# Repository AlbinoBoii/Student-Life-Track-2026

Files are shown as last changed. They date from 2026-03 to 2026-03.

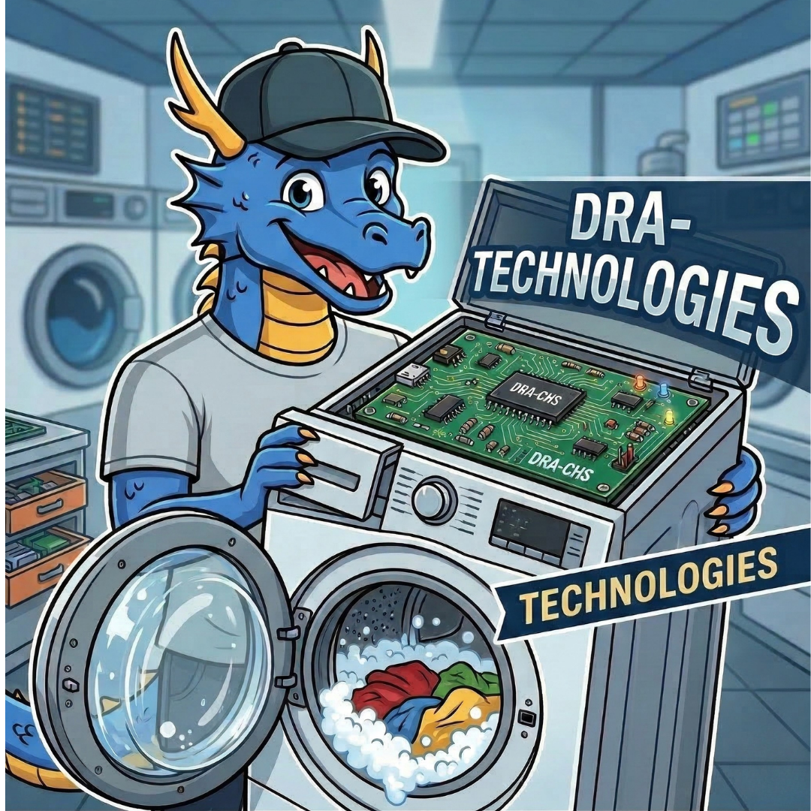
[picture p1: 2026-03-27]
Images/drawasher.png

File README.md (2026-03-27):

# 🧺 Dra-Washer Monitor – Smart Washing Machine Cycle Detection

A complete end-to-end IoT solution that transforms your **ordinary washing machine** into a smart appliance. Using an ESP32 microcontroller and vibration sensors, the system detects wash cycles in real-time and provides a powerful dashboard for monitoring and ML-based cycle classification.

**Perfect for**: Dorm laundry tracking, shared housing, smart home enthusiasts, IoT/ML learning projects.

---

## 🚀 Quick Start (5 Minutes)

### 1. **Access the Dashboard**
- Navigate to: `https://<your-azure-function-url>/api/dashboard`
- You'll see live streaming data from your ESP32

### 2. **Check Device Status**
- Look at the top-right corner for the **Online/Offline indicator**
- 🟢 Green = Device connected and sending data
- 🔴 Red = No data for 10+ minutes

### 3. **Explore Three Tabs**
- **Live**: Real-time washing machine vibration (refreshes every 10 seconds)
- **Historical**: Browse past cycles with date/time filters
- **ML Training**: Label historical data to train custom models

---

## 📋 Table of Contents

- [What is the Dra-Washer Monitor?](#what-is-the-dra-washer-monitor)
- [System Architecture](#system-architecture)
- [Getting Started](#getting-started)
- [Using the Dashboard](#using-the-dashboard)
- [Data Analysis & Aggregation](#-data-analysis--aggregation)
- [ML Training Pipeline](#ml-training-pipeline)
- [Project Structure](#project-structure)
- [Troubleshooting](#troubleshooting)
- [Contributing](#contributing)

---

## 💡 What is the Dra-Washer Monitor?

The **Dra-Washer Monitor** is a four-part system:

1. **Edge Device (ESP32)**: Collects vibration data via an accelerometer attached to the washing machine
2. **Cloud Backend (Azure)**: Stores data securely and provides a REST API
3. **Web Dashboard**: Real-time monitoring, historical analysis, and **interactive ML training**
4. **ML Pipeline**: Train custom models on your washing machine's unique vibration signature and deploy them back to the ESP32

### Why This Matters
- 🎯 **Solves a real problem**: Know when your laundry is done without constant checking
- 🔬 **Learn full-stack IoT**: Signal processing, cloud architecture, ML, and embedded systems
- 📊 **Your data, your model**: Train on your specific washing machine, not cloud-based generic models
- 💰 **Ultra-affordable**: Using existing hardware; only Azure Table Storage costs pennies per month

---

## 🏗️ System Architecture

```
┌─────────────────────────────────────────────────────────────────┐
│                        YOUR WASHING MACHINE                      │
│  ┌──────────────────────────────────────────────────────────┐   │
│  │  ESP32 + MPU6050 Accelerometer (10Hz sampling)          │   │
│  │  • Raw acceleration (ax, ay, az)                         │   │
│  │  • Compute motion_score & motion_avg                     │   │
│  │  • State machine (IDLE/RUNNING/SPINDRY)                  │   │
│  └──────────────┬───────────────────────────────────────────┘   │
└─────────────────┼──────────────────────────────────────────────┘
                  │ HTTP POST (every 2.5 sec during cycles)
                  │ Batched sensor data + device_id
                  ▼
        ┌─────────────────────┐
        │  Azure Functions    │
        │  /api/ingest → POST │
        │  /api/samples → GET │
        │  /api/label → PATCH │
        │  /api/dashboard→GET │
        └──────────┬──────────┘
                   │
        ┌──────────▼──────────┐
        │ Azure Table Storage │
        │   (washersensordata)│
        │  Stores all telemetry
        │  & user labels      │
        └──────────┬──────────┘
                   │
        ┌──────────▼──────────────────┐
        │   Your Web Browser (or app) │
        │                             │
        │  📊 Live Tab                │
        │    - Real-time charts       │
        │    - Device status          │
        │                             │
        │  📈 Historical Tab          │
        │    - Date range filters     │
        │    - Motion analysis        │
        │                             │
        │  🤖 ML Training Tab         │
        │    - Label cycles           │
        │    - Export CSV             │
        └──────────┬──────────────────┘
                   │
        ┌──────────▼──────────────────┐
        │   Local ML Training         │
        │   (train_model.py)          │
        │                             │
        │  1. Load labeled CSV        │
        │  2. Train Random Forest     │
        │  3. Evaluate metrics        │
        │  4. Generate C++ header     │
        └──────────┬──────────────────┘
                   │
        ┌──────────▼──────────────────┐
        │  Deploy to ESP32            │
        │  washer_model.h             │
        │  ↓                          │
        │  Custom cycle detection!    │
        └─────────────────────────────┘
```

---

## 🛠️ Getting Started

### Prerequisites
- **ESP32 Development Board** (any variant)
- **MPU6050 Accelerometer** module
- **Micro USB cable** for ESP32 programming
- **WiFi network** with internet access
- **Azure account** (for cloud backend)
- **Python 3.8+** (for ML training)

---

## ⚙️ Configuration Files (Create These Before Deployment)

### 1. ESP32 Secrets File
Create `washer_monitor/secrets.h` with your WiFi and API credentials. The firmware is configured for **Enterprise WiFi (PEAP)** (common in university campuses like NUS).

```cpp
#pragma once

// WiFi Configuration (Enterprise / PEAP)
#define WIFI_SSID     "your_wifi_name"
#define EAP_IDENTITY  "your_student_id@domain.edu"
#define EAP_USERNAME  "your_student_id@domain.edu"
#define EAP_PASSWORD  "your_portal_password"

// Azure Function API
#define AZURE_FUNCTION_URL "https://your-function.azurewebsites.net/api/ingest"
#define AZURE_API_KEY      "your-random-api-key-here"

// Telegram Notifications (Optional)
#define BOT_TOKEN "your_telegram_bot_token"
#define CHAT_ID   "your_telegram_chat_id"
```

> [!WARNING]
> These files are listed in `.gitignore` to prevent them from being committed to GitHub. However, they remain in your local folder. **Before zipping or sharing your project folder, ensure these files are removed!**

**Where to get these:**
- **WIFI_SSID/WIFI_PASSWORD**: Your home/dorm WiFi credentials
- **API_ENDPOINT**: Deployed Azure Function URL (you'll get this after Step 1 below)
- **INGEST_API_KEY**: Create a strong random string (e.g., `openssl rand -hex 32`)
- **TELEGRAM_BOT_TOKEN/CHAT_ID**: Optional - get from @BotFather on Telegram

### 2. Azure Functions Local Settings
Create `Azure/local.settings.json` for local development (excluded from git):

```json
{
  "IsEncrypted": false,
  "Values": {
    "AzureWebJobsStorage": "DefaultEndpointsProtocol=https;AccountName=yourstorageaccount;AccountKey=your-account-key;EndpointSuffix=core.windows.net",
    "AZURE_STORAGE_CONNECTION_STRING": "DefaultEndpointsProtocol=https;AccountName=yourstorageaccount;AccountKey=your-account-key;EndpointSuffix=core.windows.net",
    "INGEST_API_KEY": "your-strong-random-api-key-here",
    "FUNCTIONS_WORKER_RUNTIME": "python"
  },
  "Host": {
    "CORS": "*"
  }
}
```

**Where to get these:**
- **AccountName**: Your Azure Storage account name
- **AccountKey**: Primary access key from Storage account → Access keys
- **AZURE_STORAGE_CONNECTION_STRING**: Full connection string from the same location
- **INGEST_API_KEY**: Must match the value in `secrets.h` above

**IMPORTANT**: Never commit these files to git. They're already in `.gitignore`.

---

### Step 1: Deploy Azure Backend

1. **Clone this repository**
   ```bash
   git clone https://github.com/yourusername/Student-Life-Track-2026.git
   cd Student-Life-Track-2026
   ```

2. **Create `Azure/local.settings.json`** (see [Configuration Files](#-configuration-files-create-these-before-deployment) section above)

3. **Deploy Azure Functions** 
   - Option A: Using Azure CLI
     ```bash
     cd Azure
     az login
     az functionapp create --resource-group <your-rg> --consumption-plan-location <region> --runtime python --functions-version 4 --name <your-function-name>
     az functionapp deployment source config-zip --resource-group <your-rg> --name <your-function-name> --src-path function.zip
     ```
   - Option B: Using Azure Portal
     - Create a Function App resource
     - Upload the Python code from `Azure/function_app.py`
     - Set Application Settings with values from `local.settings.json`

4. **Note your Function URL**
   - It will be: `https://<your-function-name>.azurewebsites.net`
   - Copy this to `washer_monitor/secrets.h` as `API_ENDPOINT`

### Step 2: Flash ESP32 Firmware

1. **Open Arduino IDE** and install ESP32 board support
   ```
   Board Manager → ESP32 by Espressif
   ```

2. **Open `washer_monitor/washer_monitor.ino`**

3. **Edit `washer_monitor/secrets.h`** with your credentials:
   ```cpp
   #define WIFI_SSID      "Your_WiFi_Name"
   #define EAP_PASSWORD   "Your_Password"
   #define AZURE_FUNCTION_URL "https://<function-name>.azurewebsites.net/api/ingest"
   #define AZURE_API_KEY      "your-api-key-from-above"
   ```

4. **Connect MPU6050 to ESP32:**
   ```
   MPU6050 → ESP32
   VCC     → 3.3V
   GND     → GND
   SCL     → GPIO 22
   SDA     → GPIO 21
   ```

5. **Upload to ESP32:**
   - Select Board: "ESP32 Dev Module" (or your variant)
   - Select COM port
   - Click Upload

### Step 3: Monitor Live Data

1. Open your browser: `https://<function-name>.azurewebsites.net/api/dashboard`
2. Tap/vibrate the ESP32 to see live motion data
3. Check the device status indicator (top-right)

---

## 📊 Using the Dashboard

### Live Tab
**Real-time monitoring of your washing machine**

```
Controls:
  • Device ID: Filter by device (default: "ESP32 Washer Monitor")
  • Refresh Rate: 5s, 10s, 30s, or 1 minute
  • Backgrounds: Toggle state coloring

Display:
  • Motion Score chart (blue line)
  • 10-second average motion (orange line)
  • Colored backgrounds (green=IDLE, red=RUNNING)
  • Statistics: Total samples, avg motion, running %, etc.
```

### Historical Tab
**Review and analyze past cycles**

```
Filters:
  • Date range: Set "Since" and "Until" timestamps
  • State filter: Show only IDLE or RUNNING cycles
  • Limit: Max 10,000 samples

Actions:
  • Load Data: Fetch matching samples
  • ⬇ CSV: Export as CSV for external analysis
```

### ML Training Tab
**Build custom cycle detection for your machine**

```
Workflow:
  1. Set date filters for data you want to label
  2. Click "📂 Load Data" to load that period
  3. Click-and-drag on the motion chart to select a time range
  4. Choose label: IDLE, WASH, or SPINDRY
  5. Click "Apply Label"
  6. Repeat until you've labeled 30-50 samples of each state
  7. Click "⬇ Labelled CSV" to download

What Each Label Means:
  • IDLE: Machine at rest (baseline vibration)
  • WASH: Main wash cycle (moderate vibration)
  • SPINDRY: High-speed spin-dry (intense vibration)
```

---

## 📊 Data Analysis & Aggregation

### Time-Based Aggregation

Compress large datasets into meaningful time buckets for trend analysis:

```
Query: GET /api/samples?device_id=ESP32&aggregate=5m&format=json

Response:
{
  "count": 288,
  "aggregated": true,
  "bucket_size": "5m",
  "samples": [
    {
      "ts_ms": 1710748800000,
      "motion_score_avg": 2.45,
      "motion_score_min": 0.1,
      "motion_score_max": 8.2,
      "ax_avg": 0.15, "ax_min": -1.2, "ax_max": 1.1,
      "ay_avg": -0.05, "ay_min": -0.8, "ay_max": 0.9,
      "az_avg": 9.82, "az_min": 9.5, "az_max": 10.1,
      "motion_avg_avg": 1.8,
      "sample_count": 300,
      "running_percent": 45.5,
      "sub_state_modes": {"IDLE": 120, "WASH": 150, "SPINDRY": 30}
    },
    ...
  ]
}
```

#### Supported Aggregation Intervals

| Interval | Use Case | Typical Points for 24h |
|---|---|---|
| `1m` | Fine-grained analysis | 1,440 |
| `5m` | Cycle detection patterns | 288 |
| `15m` | Daily trends | 96 |
| `1h` | Long-term statistics | 24 |

**What Gets Aggregated:**
- **Motion metrics**: average, min, max of motion_score and motion_avg
- **Accelerometer axes**: average, min, max for ax, ay, az
- **State analysis**: percentage of time in RUNNING state
- **Sub-state distribution**: count of IDLE/WASH/SPINDRY samples
- **Sample metadata**: total samples in bucket

### Device Health Monitoring

Get comprehensive device uptime and reliability metrics:

```bash
# Query device health for last 7 days
curl "https://<your-function>/api/device-health?device_id=ESP32&days=7"
```

Response includes:

```json
{
  "device_id": "ESP32",
  "total_uptime_seconds": 604800,
  "uptime_percent": 98.5,
  "total_boots": 2,
  "boot_events": [
    {
      "boot_id": "abc123",
      "boot_ts": "2026-03-11T10:00:00+00:00",
      "samples_count": 15000,
      "last_activity": "2026-03-12T14:30:00+00:00"
    }
  ],
  "data_gaps": [
    {
      "start": "2026-03-12T05:00:00+00:00",
      "end": "2026-03-12T05:45:00+00:00",
      "duration_seconds": 2700,
      "reason": "No data (likely offline or power loss)"
    }
  ],
  "wifi_signal_stats": {
    "avg_rssi": -67,
    "min_rssi": -85,
    "max_rssi": -45,
    "samples_with_signal": 14500
  },
  "last_contact": {
    "timestamp": "2026-03-18T14:22:15+00:00",
    "age_seconds": 45,
    "status": "online"
  }
}
```

**Health Metrics Explained:**
- **uptime_percent**: % of observation period device was actively sending data
- **total_boots**: Number of device restarts detected
- **data_gaps**: Periods > 5 minutes without activity (potential issues)
- **wifi_signal_stats**: WiFi signal strength (RSSI) in dBm
  - `-67 dBm`: Strong signal
  - `-85 dBm`: Weak signal (consider repositioning)
- **last_contact**: When device was last heard from; "offline" if > 10 minutes

### Export Data for Analysis

#### CSV Export

```bash
# Download 24h of aggregated data as CSV
curl "https://<your-function>/api/samples?device_id=ESP32&aggregate=1h&format=csv&since=2026-03-18T00:00:00Z&until=2026-03-19T00:00:00Z" \
  > washer_analysis.csv
```

The CSV includes all aggregated columns and is ready for import into Excel, Python, or Tableau.

#### JSON Export (Large Datasets)

```bash
# Raw JSON with full detail (can handle large responses)
curl "https://<your-function>/api/samples?device_id=ESP32&format=json&limit=50000"
```

### Practical Examples

#### Track Washing Machine Usage Over Time

```bash
# Get hourly aggregation for the past week
curl "https://<your-function>/api/samples?device_id=ESP32&aggregate=1h&since=2026-03-11T00:00:00Z"
```

Use this to:
- Identify peak laundry times
- Calculate total RUNNING time per day
- Spot anomalies in vibration patterns

#### Monitor Device Reliability

```bash
# Check if device is healthy
curl "https://<your-function>/api/device-health?device_id=ESP32&days=30"
```

Look for:
- `uptime_percent` > 95% (acceptable)
- No large `data_gaps`
- Consistent WiFi signal (`avg_rssi` > -75 dBm)
- Recent `last_contact` (< 1 minute if running)

#### Diagnose Offline Events

```bash
# See exactly when and why device went offline
curl "https://<your-function>/api/device-health?device_id=ESP32&days=7" | jq '.data_gaps'
```

---

## 🤖 ML Training Pipeline

### Overview

Transform your labeled data into a custom cycle detector:

```
Labeled CSV
    ↓
  [train_model.py]
    ↓
  Random Forest
  Classifier
    ↓
  Accuracy Metrics
    ↓
  C++ Code Generator
    ↓
  washer_model.h
    ↓
  Deploy to ESP32
    ↓
  Custom Cycle Detection! 🎉
```

### Quick Start: Training Your Model

#### Step 1: Label Data in Dashboard
1. Go to **ML Training** tab
2. Select historical data with date filters
3. Click "📂 Load Data"
4. Click-drag to select regions and label them
5. Repeat until you have 30-50 samples per class
6. Click "⬇ Labelled CSV"

#### Step 2: Install Python Dependencies
```bash
cd Student-Life-Track-2026
pip install -r requirements.txt

# Or manually:
pip install pandas scikit-learn joblib numpy matplotlib
```

#### Step 3: Train the Model
```bash
# Basic (looks for washer_labelled_samples.csv)
python train_model.py

# Or specify custom paths
python train_model.py --data my_data.csv --output my_model.h
```

#### Step 4: Review Results
The script outputs:
- ✅ Cross-validation accuracy (5-fold)
- ✅ Test set accuracy
- ✅ Confusion matrix
- ✅ Feature importance
- ✅ Classification report

Example output:
```
Mean Accuracy: 0.942 (+/- 0.025)
Test Accuracy: 0.956

Feature Importance:
    motion_score: 0.450
    motion_avg: 0.380
    ax: 0.085
    ay: 0.062
    az: 0.023
```

#### Step 5: Deploy to ESP32
```bash
# Copy the generated header
cp washer_model.h washer_monitor/washer_model.h

# Edit washer_monitor.ino to include and use it:
#include "washer_model.h"

// In your loop:
WasherFeatures features = {
  motion_score: current_score,
  motion_avg: current_avg,
  ax, ay, az
};
uint8_t state = WasherStateClassifier::predict(features);
```

Then upload to ESP32 and enjoy autonomous cycle detection! 🎉

### Re-training

As you collect more data:
1. Label additional samples in the dashboard
2. Export updated CSV
3. Run `train_model.py` again
4. Copy new `washer_model.h`
5. Re-upload to ESP32

Each re-training improves accuracy!

---

## 📁 Project Structure

```
Student-Life-Track-2026/
│
├── 📄 README.md                      ← You are here!
│
├── 🔷 Azure/
│   ├── function_app.py               ← Cloud backend (POST/GET/PATCH endpoints)
│   ├── requirements.txt
│   └── (deployment configs)
│
├── 🔷 washer_monitor/                ← ESP32 Firmware
│   ├── washer_monitor.ino            ← Main sketch
│   ├── config.h                      ← WiFi, API credentials
│   ├── mpu_sensor.cpp                ← Accelerometer driver
│   ├── signal_processing.cpp         ← EMA filter, motion detection
│   ├── wifi_manager.cpp              ← WiFi + HTTP client
│   ├── azure_poster.cpp              ← JSON batching & POST
│   └── washer_model.h                ← Generated ML model (after training)
│
├── 🐍 train_model.py                 ← ML training script
├── requirements.txt                  ← Python dependencies
│
└── 📊 washer_labelled_samples.csv     ← Your labeled data (from dashboard)
```

### Key Files Explained

**Azure/function_app.py** - Cloud API
- `POST /api/ingest` – Device sends batched sensor data
- `GET /api/samples` – Dashboard fetches data (supports filtering)
- `PATCH /api/label` – Dashboard labels samples
- `GET /api/dashboard` – Returns self-contained HTML dashboard

**washer_monitor/washer_monitor.ino** - ESP32 Main Loop
- Reads MPU6050 at 10Hz
- Computes motion metrics
- POSTs data every 2.5 seconds during cycles

**train_model.py** - ML Trainer
- Loads labeled CSV from dashboard
- Trains Random Forest (50 trees, max depth 10)
- Evaluates with cross-validation
- Generates C++ header for ESP32

---

## 🐛 Troubleshooting

### Dashboard Issues

#### "Cannot connect to dashboard"
- ✓ Check Azure Functions deployment status
- ✓ Verify CORS is enabled (if accessing from different domain)
- ✓ Check connection string and API key are set

#### Data shows as "Offline"
- ✓ ESP32 device: Check WiFi connection
- ✓ Verify INGEST_API_KEY matches dashboard backend
- ✓ Check Azure Table Storage quota (rarely hit)
- ✓ Look at ESP32 serial monitor for error messages

#### Charts not updating in Live tab
- ✓ Check browser console for JavaScript errors
- ✓ Verify device is sending data (check last timestamp)
- ✓ Try refreshing the page

### ESP32 Issues

#### ESP32 won't connect to WiFi
- ✓ Verify SSID and password in `config.h`
- ✓ Check if 5GHz WiFi (use 2.4GHz instead)
- ✓ Open serial monitor (9600 baud) to see error messages
- ✓ Re-upload firmware after changes

#### No data appearing in dashboard
- ✓ Check that ESP32 is powered and running
- ✓ Look at serial output for HTTP POST errors
- ✓ Verify API_ENDPOINT URL is correct
- ✓ Verify INGEST_API_KEY matches Azure backend

#### Accelerometer readings are wrong
- ✓ Check MPU6050 wiring (I2C: SCL=GPIO22, SDA=GPIO21)
- ✓ Verify I2C pull-up resistors are present (4.7kΩ typical)
- ✓ Run I2C scanner to verify MPU6050 is detected
- ✓ Check for loose connections

### ML Training Issues

#### "No labeled data found"
- ✓ Make sure you labeled data in the dashboard's ML tab
- ✓ Click "⬇ Labelled CSV" to download the right file
- ✓ Verify CSV has a `sub_state` column with IDLE/WASH/SPINDRY

#### Low model accuracy
- ✓ Label more samples (aim for 50+ per class)
- ✓ Ensure labels are accurate (watch the chart when labeling)
- ✓ Collect data under different conditions
- ✓ Check for imbalanced datasets

#### Python dependency errors
```bash
# Make sure you're using Python 3.8+
python --version

# Reinstall all dependencies
pip install -r requirements.txt --force-reinstall
```

---

## 🚀 Advanced Usage

### Custom Azure Deployment

See `Azure/function_app.py` for endpoint details. You can:
- Add custom filtering logic in `/api/samples`
- Implement data retention policies
- Add user authentication (currently open/anonymous)
- Scale to multiple devices

### ESP32 Customization

Modify `washer_monitor/config.h` to tune:
- Sampling frequency (currently 10Hz)
- EMA filter alpha (motion smoothing)
- State detection thresholds
- HTTP batch interval

### Model Improvements

The `train_model.py` script can be extended to:
- Support more than 3 classes
- Export to TensorFlow Lite for better ESP32 performance
- Use neural networks instead of Random Forest
- Perform hyperparameter tuning (GridSearchCV)

---

## 📚 Learning Resources

- **Signal Processing**: Read about EMA filters and motion detection
- **ML Fundamentals**: Random Forest classifiers, cross-validation, feature importance
- **Embedded Systems**: Arduino IDE, ESP32 capabilities, I2C protocol
- **Cloud Services**: Azure Functions, Table Storage, REST APIs

---

## 🤝 Contributing

We welcome contributions! Areas for improvement:

- [ ] Support for multiple washer types/models
- [ ] Deep learning models (TensorFlow Lite)
- [ ] Mobile app (React Native)
- [ ] Energy consumption tracking
- [ ] Automated data collection heuristics
- [ ] Better feature engineering pipeline

---

## 🙋 Support & Questions

- 📖 Check this README first
- 🐛 Search existing GitHub issues
- 💬 Open a new issue with details
- ✉️ Email: [contact info]

---

## 🎉 Credits

Built with ❤️ for students who are tired of forgetting their laundry.

**Technologies**: ESP32, Azure Functions, Chart.js, scikit-learn, Random Forest

---

**Happy laundry monitoring! 🧺**

*Last updated: March 2026*

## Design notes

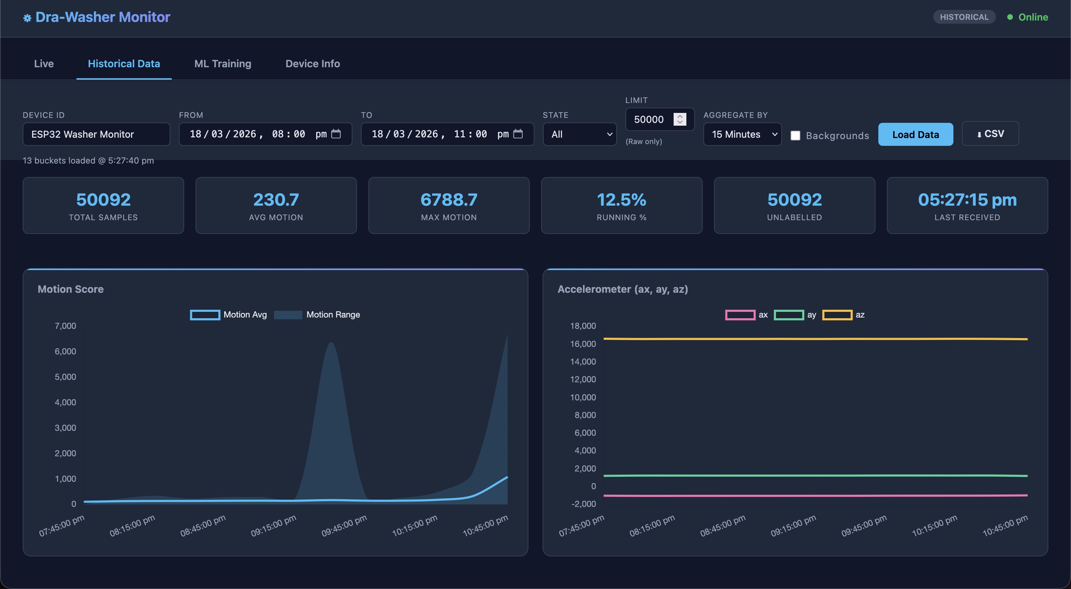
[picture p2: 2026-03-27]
Images/Dashboard (Historical Data View).jpg.jpg

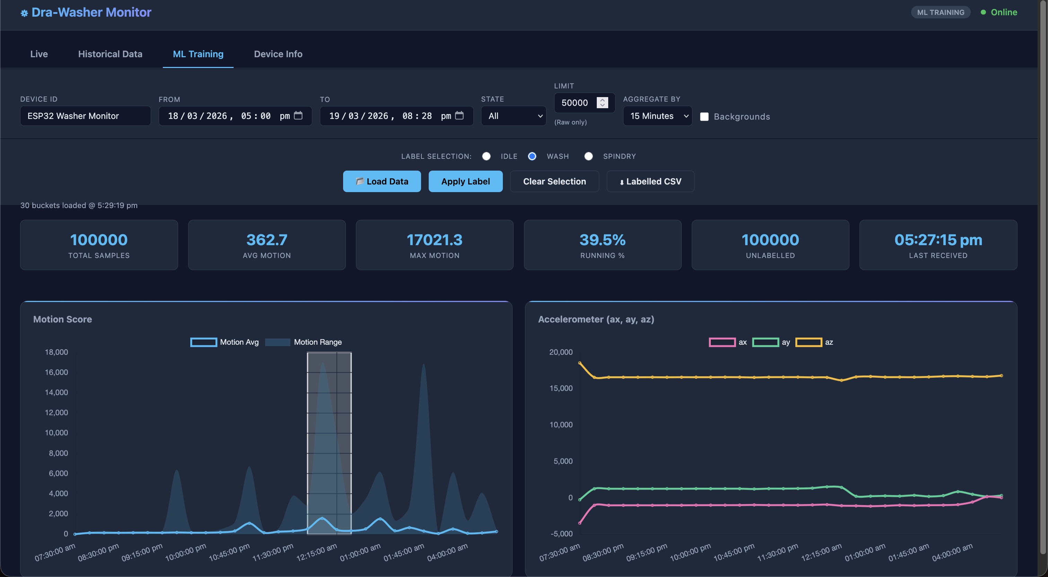
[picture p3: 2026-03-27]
Images/Dashboard (ML Training).jpg

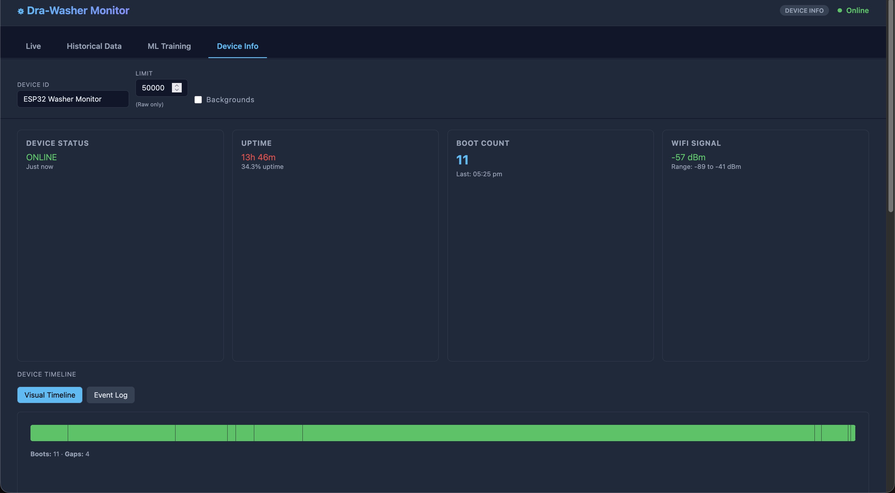
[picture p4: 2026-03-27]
Images/Dashboard (Device Info View).jpg

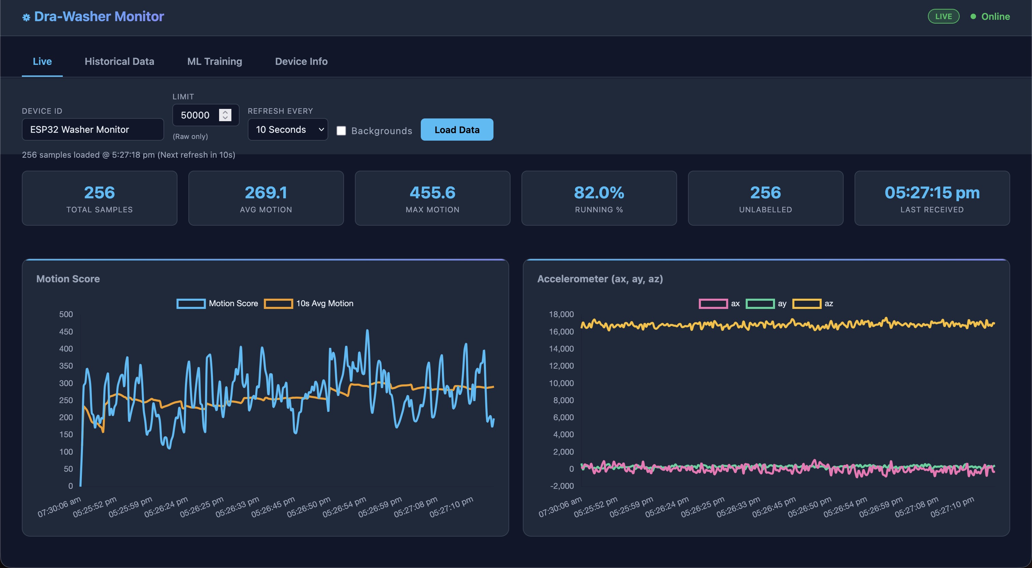
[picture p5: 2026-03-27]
Images/Dashboard (Live View).jpg

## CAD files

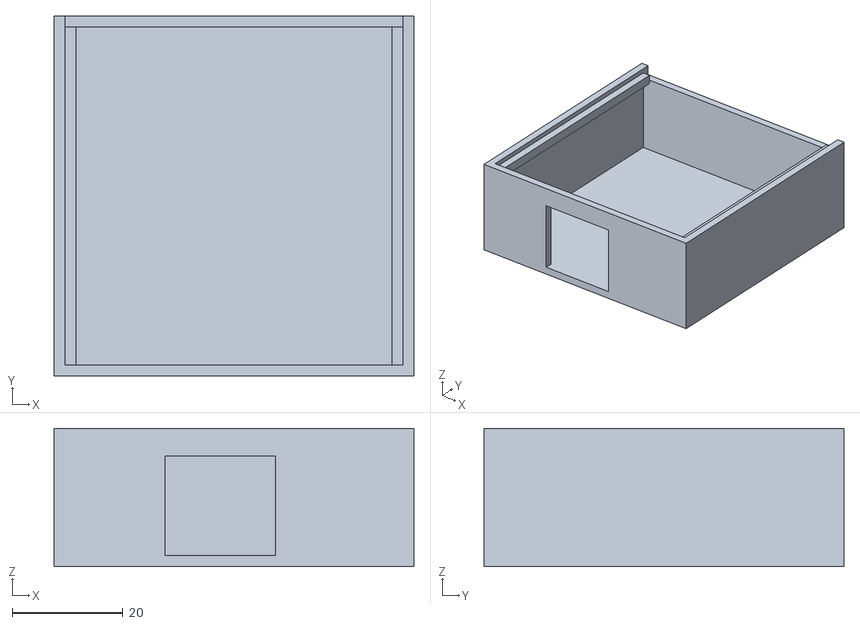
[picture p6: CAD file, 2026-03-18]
3d printed box/sliding_box_body.stl
65.0 x 65.0 x 25.0

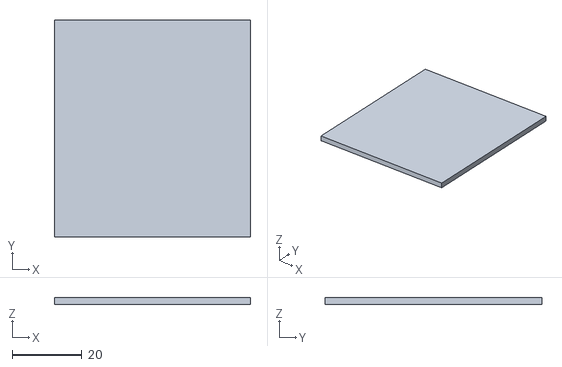
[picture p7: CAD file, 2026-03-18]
3d printed box/sliding_box_lid.stl
56.4 x 62.4 x 2.00

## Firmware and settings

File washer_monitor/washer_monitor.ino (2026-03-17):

#include <WiFi.h>

#include "config.h"
#include "wifi_manager.h"
#include "telegram_manager.h"
#include "mpu_sensor.h"
#include "washer_logic.h"
#include "serial_logger.h"
#include "azure_poster.h"

static unsigned long lastSampleMs = 0;
static unsigned long lastStatusMs = 0;

void printStatus() {
  Serial.print("[STATUS] wifi=");
  Serial.print(isWiFiConnected() ? "UP" : "DOWN");
  Serial.print(" ip=");

  if (isWiFiConnected()) {
    Serial.print(WiFi.localIP());
  } else {
    Serial.print("no-ip");
  }

  Serial.print(" motion=");
  Serial.print(getMotionEma(), 2);
  Serial.print(" state=");
  Serial.print(washerStateName());
  Serial.print(" pendingTelegram=");
  Serial.println(hasPendingTelegram() ? "YES" : "NO");
}

void setup() {
  Serial.begin(115200);
  delay(1000);

  Serial.println();
  Serial.println("Booting...");

  setupMPU();
  initWasherLogic();
  serialLoggerBegin();
  initAzurePoster();

  connectWiFi(30000);
  queueTelegram(String(DEVICE_NAME) + ": boot complete.");
}

void loop() {
  unsigned long now = millis();

  ensureWiFi();
  processPendingTelegram();

  if (now - lastSampleMs >= SAMPLE_INTERVAL_MS) {
    lastSampleMs = now;
    sampleMotion();
    serialLoggerLogSample();
    bufferSampleForAzure();
  }

  flushAzureBatch();

  if (now - lastStatusMs >= STATUS_PRINT_MS) {
    lastStatusMs = now;
    printStatus();
  }
}

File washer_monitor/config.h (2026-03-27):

#pragma once
#include <Arduino.h>

// =========================
// DEVICE / PINS
// =========================
constexpr char DEVICE_NAME[] = "ESP32 Washer Monitor";
constexpr int SDA_PIN = 21;
constexpr int SCL_PIN = 22;

// =========================
// DETECTION TUNING
// =========================
constexpr unsigned long SAMPLE_INTERVAL_MS = 100;   // 10 Hz
constexpr float EMA_ALPHA                  = 0.18f;

constexpr float START_THRESHOLD            = 190.0f;
constexpr float STOP_THRESHOLD             = 150.0f;

constexpr unsigned long START_CONFIRM_MS   = 30000UL; // 25s
constexpr unsigned long STOP_CONFIRM_MS    = 30000UL;  // 25s

constexpr bool SEND_START_ALERT            = true;

// =========================
// RETRY / STATUS
// =========================
constexpr unsigned long WIFI_RETRY_MS      = 10000UL;
constexpr unsigned long TELEGRAM_RETRY_MS  = 15000UL;
constexpr unsigned long STATUS_PRINT_MS    = 1000UL;


// =========================
// SERIAL LOGGING
// =========================
constexpr bool SERIAL_LOG_ENABLED         = true;
constexpr unsigned long SERIAL_LOG_MS     = 100;   // log every 100 ms

// =========================
// AZURE (data sink)
// =========================
constexpr bool   AZURE_ENABLED         = true;  // azure kill switch
constexpr int    AZURE_BATCH_SIZE      = 25;     // samples per POST batch
constexpr unsigned long AZURE_FLUSH_MS = 2500UL; // max time between POSTs

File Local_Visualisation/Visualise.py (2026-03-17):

import pandas as pd
import matplotlib.pyplot as plt
import glob
import os
import sys

def main():
    # If filenames are passed as arguments, use them. Otherwise, find all.
    if len(sys.argv) > 1:
        target_files = sys.argv[1:]
    else:
        script_dir = os.path.dirname(os.path.abspath(__file__))
        search_pattern = os.path.join(script_dir, "washer_log_*.csv")
        log_files = glob.glob(search_pattern)
        if not log_files:
            print(f"No washer_log CSV files found in {script_dir}.")
            print("Usage: python Visualise.py [path_to_csv1] [path_to_csv2] ...")
            sys.exit(1)
        target_files = sorted(log_files) # Sort to have consistent order
    
    print(f"Visualizing files: {', '.join(target_files)}")

    # Create a figure with two subplots: one for motion, one for x, y, z acceleration
    fig, (ax1, ax2) = plt.subplots(2, 1, figsize=(12, 8), sharex=True)

    colors_motion = ['purple', 'blue', 'green', 'orange']
    colors_avg = ['red', 'darkred', 'crimson', 'pink']
    
    x_label = 'Sample Index'

    for idx, target_file in enumerate(target_files):
        # Read the CSV
        try:
            df = pd.read_csv(target_file)
        except Exception as e:
            print(f"Error reading {target_file}: {e}")
            continue

        # Rename new Azure CSV columns to legacy names for compatibility
        rename_map = {
            'ts_ms': 'esp_ms',
            'motion_score': 'motion',
            'motion_avg': 'avg_motion_10s'
        }
        df = df.rename(columns=rename_map)

        # Ensure data types are correct
        for col in ['esp_ms', 'ax', 'ay', 'az', 'motion', 'avg_motion_10s']:
            if col in df.columns:
                df[col] = pd.to_numeric(df[col], errors='coerce')

        # Use received_at (converted to datetime) for the X-axis if available
        if 'received_at' in df.columns and not df['received_at'].isna().all():
            df['received_at'] = pd.to_datetime(df['received_at'])
            x_col = df['received_at']
            x_label = 'Time Received'
        # Fallback to esp_ms (converted to minutes relative to start) if available
        elif 'esp_ms' in df.columns and not df['esp_ms'].isna().all():
            x_col = (df['esp_ms'] - df['esp_ms'].iloc[0]) / 60000.0
            x_label = 'Time (minutes since start)'
        else:
            x_col = df.index
            x_label = 'Sample Index'

        file_basename = os.path.basename(target_file)
        
        # Set distinct contrasting colors based on index rather than hardcoding names
        base_color = colors_motion[idx % len(colors_motion)]
        avg_color = colors_avg[idx % len(colors_avg)]

        # Plot Motion
        if 'motion' in df.columns:
            # Make the raw motion slightly more transparent if we have average
            alpha_val = 0.3 if 'avg_motion_10s' in df.columns else 0.8
            ax1.plot(x_col, df['motion'], label=f'Motion: {file_basename}', color=base_color, alpha=alpha_val)
            
            if 'avg_motion_10s' in df.columns:
                ax1.plot(x_col, df['avg_motion_10s'], label=f'Avg (10s): {file_basename}', color=avg_color, linewidth=2)

        # Plot ax, ay, az
        if all(col in df.columns for col in ['ax', 'ay', 'az']):
            ax2.plot(x_col, df['ax'], label=f'X: {file_basename}', alpha=0.5)
            ax2.plot(x_col, df['ay'], label=f'Y: {file_basename}', alpha=0.5)
            ax2.plot(x_col, df['az'], label=f'Z: {file_basename}', alpha=0.5)

    ax1.set_ylabel('Motion Value')
    ax1.set_ylim(0, 9000)
    ax1.set_title('Washer Motion Data Overlay')
    ax1.grid(True, linestyle='--', alpha=0.6)
    
    # Put legend outside if it gets too large, but upper right is fine for 2 files
    ax1.legend(loc='upper right', fontsize='small')

    ax2.set_ylabel('Acceleration')
    ax2.set_xlabel(x_label)
    ax2.grid(True, linestyle='--', alpha=0.6)
    ax2.legend(loc='upper right', fontsize='small')

    # Set x-axis limit starting from 10 mins 30s (10.5 minutes)
    plt.xlim(left=0)

    plt.tight_layout()
    plt.show()

if __name__ == "__main__":
    main()

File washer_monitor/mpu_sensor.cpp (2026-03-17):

#include "mpu_sensor.h"

#include <Wire.h>
#include <MPU6050.h>
#include <math.h>

#include "config.h"
#include "washer_logic.h"

static MPU6050 mpu;
static float motionEma = 0.0f;
static float lastMagnitude = 0.0f;
static bool firstSample = true;

// 10-second rolling average (100 samples at 10Hz)
#define MOTION_HIST_LEN 100
static float motionHistory[MOTION_HIST_LEN];
static int histIdx = 0;
static int histCount = 0;
static float motionSum = 0.0f;
static float motionAvg10s = 0.0f;

static SensorSample latestSample = {0, 0, 0, 0, 0.0f, 0.0f};

void setupMPU() {
  Wire.begin(SDA_PIN, SCL_PIN);

  Serial.println("[MPU6050] Initializing...");
  mpu.initialize();

  if (mpu.testConnection()) {
    Serial.println("[MPU6050] Connected!");
  } else {
    Serial.println("[MPU6050] Connection failed");
  }
}

void sampleMotion() {
  int16_t ax, ay, az;
  mpu.getAcceleration(&ax, &ay, &az);

  float magnitude = sqrtf(
    (float)ax * (float)ax +
    (float)ay * (float)ay +
    (float)az * (float)az
  );

  if (firstSample) {
    lastMagnitude = magnitude;
    firstSample = false;
  } else {
    float delta = fabsf(magnitude - lastMagnitude);
    lastMagnitude = magnitude;
    motionEma = EMA_ALPHA * delta + (1.0f - EMA_ALPHA) * motionEma;
    
    // Update 10-second moving average
    if (histCount == MOTION_HIST_LEN) {
      motionSum -= motionHistory[histIdx];
    } else {
      histCount++;
    }
    motionHistory[histIdx] = motionEma;
    motionSum += motionEma;
    histIdx = (histIdx + 1) % MOTION_HIST_LEN;
    
    motionAvg10s = motionSum / (float)histCount;

    // Use moving average for state detection!
    updateWasherState(motionAvg10s);
  }

  latestSample.esp_ms = millis();
  latestSample.ax = ax;
  latestSample.ay = ay;
  latestSample.az = az;
  latestSample.motion = motionEma;
  latestSample.motion_avg = motionAvg10s;
}

float getMotionEma() {
  return motionEma;
}

SensorSample getLatestSample() {
  return latestSample;
}

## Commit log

2026-03-13 First commit from local
    [washer_log_20260313_223644.csv, washer_log_20260313_231123.csv]
2026-03-13 removed useless csv in ESP32 folder
    [washer_log_20260313_223644.csv]
2026-03-14 switch from render backend to azure
2026-03-18 updated stl models
    [sliding_box_body.stl, sliding_box_lid.stl]
2026-03-18 Fix dashboard syntax error in downloadLabelledCSV function
    Changed escape sequence from "\\n" to String.fromCharCode(10) to prevent
    unescaped line break syntax error and undefined switchTab reference error.
